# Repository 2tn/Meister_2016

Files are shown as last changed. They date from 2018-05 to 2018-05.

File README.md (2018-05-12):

# Meister_2016
2016年度Meister鳥人間プロジェクトに搭載した飛行ロガー、「われのロガー3」のプログラム及び発注基板データ。



搭載したパーツは
- LPC11U35FHI33 (メインマイコン)
- MPU9250 (9軸センサー)
- MPL3115A2 (気圧センサー)
- NEO-7M (GPS)
- LTC4055 (LiPo充電制御チップ)
- TPS63001DRCT (3.3V DC/DCコンバーター)
- TWE-Lite (各搭載センサーとの通信用)

## われのロガー3
メインマイコンのプログラム。EMとFMのプロジェクトがあるが、FMのほうが最終的な完成版。
## 機速計
機速計のプログラム。よく覚えていない。
## 表示器 (7セグLED)
表示器のプログラム
## 表示器 (Android)
搭載したスマホ表示器のプログラム
## ダウンリンク
機体に積んであるスマホから、携帯回線経由で常時データをサーバーにアップロードしている。

このプログラムはそのデータを地上にいる観客がスマホで見るためのもの
## 基板
発注した基板データ、たくさんある…
- main_16

  われのロガー3の基板データ
- main_16_writer

  われのロガー3専用のデバッグ用機器、われのロガー3の下にはめてUSBでPCと接続することで、われのロガー3をデバッグできる。
  プログラムは、トラ技ARMライターのものをつかう。
- main_15

  2015年度の基板を回路図に落とし込んだもの  
- display

  表示器の回路設計図
- speedmeter

  機速計の回路設計図
- TWE-Lite_USB

  TWE LiteにUSB-UART変換チップをくっつけて、PCで使いやすくするための基板

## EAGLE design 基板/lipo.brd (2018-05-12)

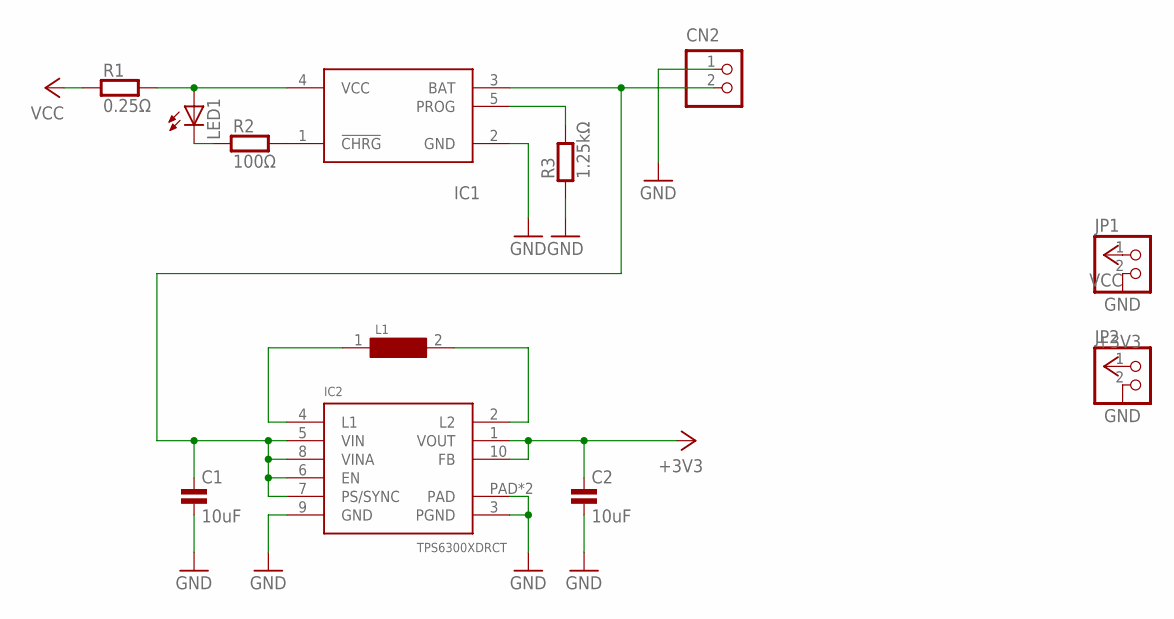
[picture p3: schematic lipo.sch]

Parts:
C1, C2: 10uF; 0603
CN2: S2B-PH-K-S
IC1: LTC4054; TSOT23-5
IC2: TPS6300XDRCT; S-PVSON-N10
JP1, JP2: PINHD-1X2; 1X02
L1: VLF4012ST
LED1: LEDSML0603; SML0603
R1: 0.25Ω; 0603
R2: 100Ω; 0603
R3: 1.25kΩ; 0603

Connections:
+3V3: C2.1, IC2.1 (VOUT), IC2.10 (FB), JP2.1
GND: C1.2, C2.2, CN2.1, IC1.2 (GND), IC2.3 (PGND), IC2.9 (GND), IC2.PAD, IC2.PAD@1 (PAD), JP1.2, JP2.2, R3.1
unnamed: IC1.5 (PROG), R3.2
unnamed: IC1.4 (VCC), LED1.A, R1.2
unnamed: IC1.1 (!CHRG!), R2.2
unnamed: LED1.C, R2.1
unnamed: IC2.4 (L1), L1.1
unnamed: IC2.2 (L2), L1.2
unnamed: C1.1, CN2.2, IC1.3 (BAT), IC2.5 (VIN), IC2.6 (EN), IC2.7 (PS/SYNC), IC2.8 (VINA)
VCC: JP1.1, R1.1

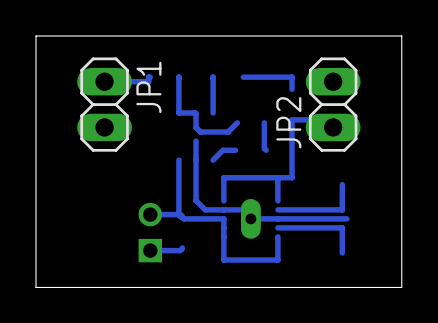
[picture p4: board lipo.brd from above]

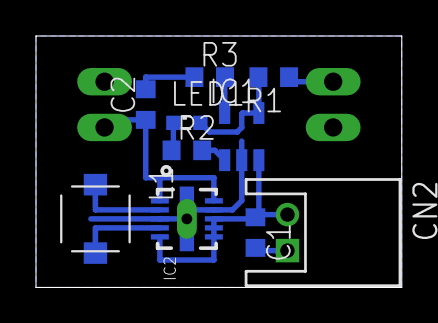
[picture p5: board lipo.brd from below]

Board: 2 copper layers, 20.3 x 14.0 mm, 12 parts (10 on the bottom side), 10 nets.

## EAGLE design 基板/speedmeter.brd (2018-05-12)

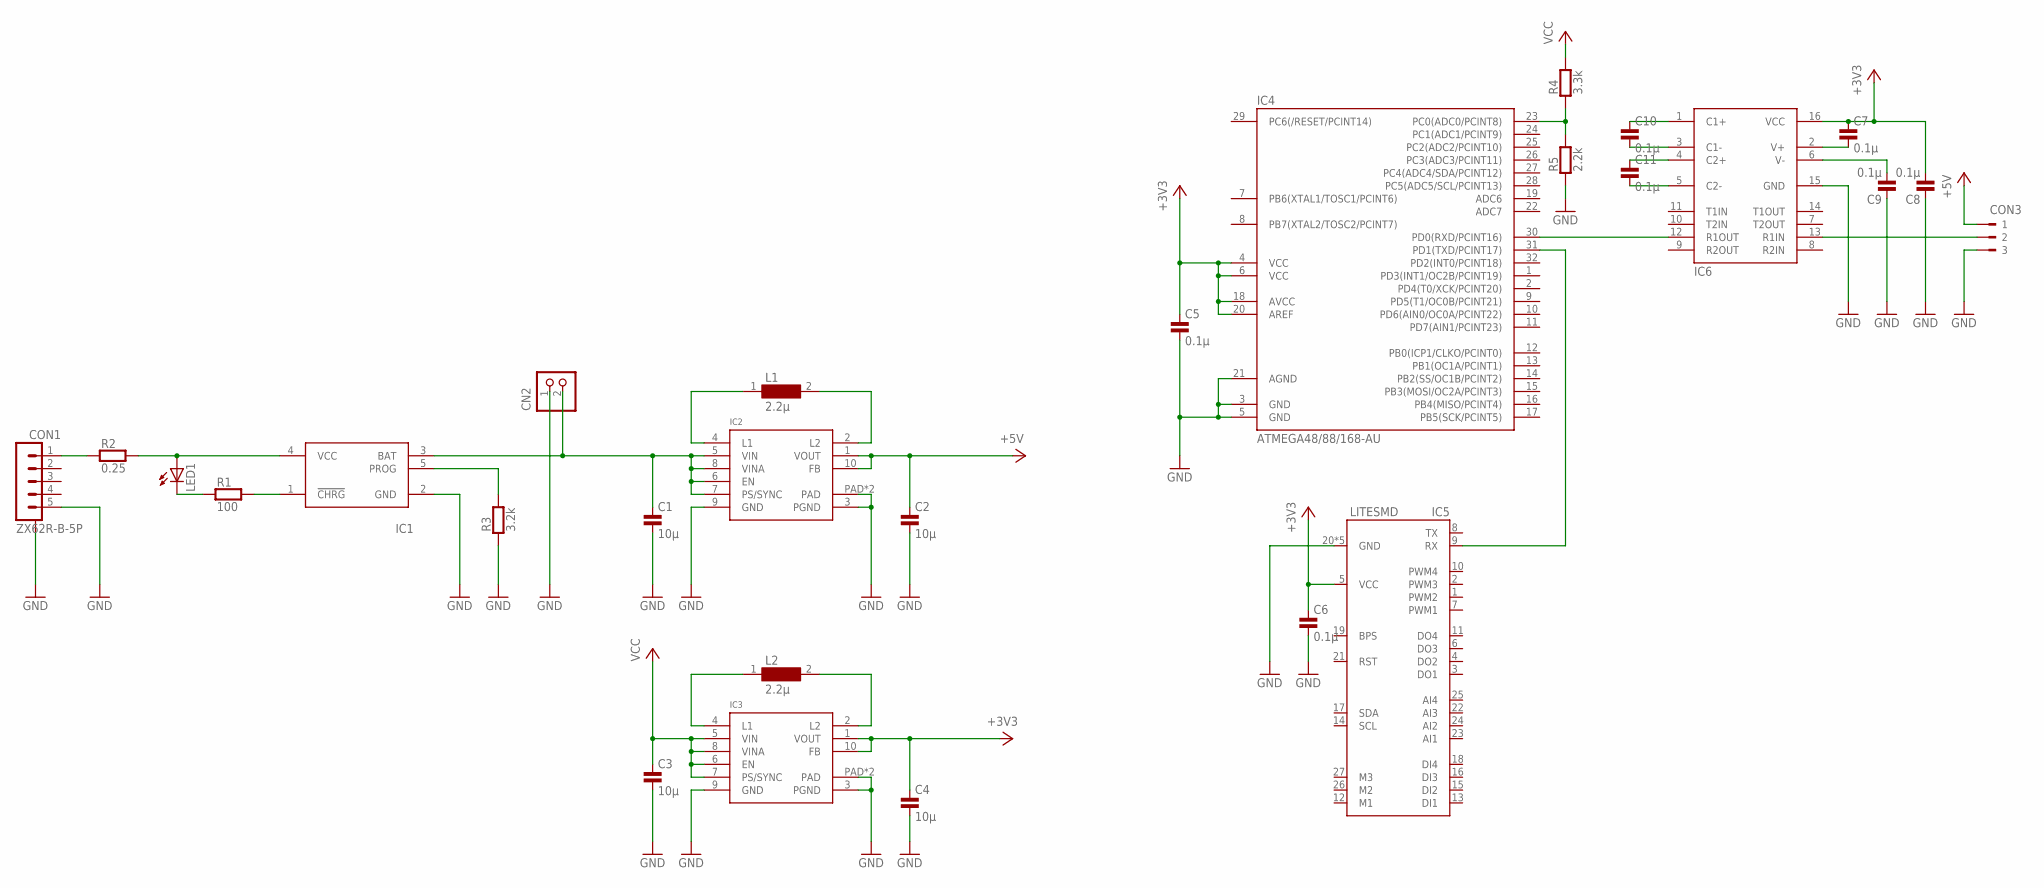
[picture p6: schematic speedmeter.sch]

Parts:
C1, C2, C3, C4: 10μ; 0603
C5, C6, C7, C8, C9, C10, C11: 0.1μ; 0603
CN2: S2B-PH-K-S
CON1: ZX62R-B-5P; MICRO-B
CON3: 180-3
IC1: LTC4054; TSOT23-5
IC2, IC3: TPS6300XDRCT; S-PVSON-N10
IC4: ATMEGA48/88/168-AU; TQFP32-08
IC5: LITESMD; LITE
IC6: ADM3202ARN; SOP16
L1, L2: 2.2μ; VLF4012ST
LED1: LEDSML0603; SML0603
R1: 100; 0603
R2: 0.25; 0603
R3: 3.2k; 0603
R4: 3.3k; 0603
R5: 2.2k; 0603

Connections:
+3V3: C4.1, C5.1, C6.1, C7.1, C8.2, IC3.1 (VOUT), IC3.10 (FB), IC4.4 (VCC), IC4.6 (VCC), IC4.18 (AVCC), IC4.20 (AREF), IC5.5 (VCC), IC6.16 (VCC)
+5V: C2.1, CON3.1, IC2.1 (VOUT), IC2.10 (FB)
GND: C1.2, C2.2, C3.2, C4.2, C5.2, C6.2, C8.1, C9.1, CN2.1, CON1.5 (1.VBUS), CON1.CASE@1, CON1.CASE@2, CON1.CASE@3, CON1.CASE@4, CON3.3, IC1.2 (GND), IC2.3 (PGND), IC2.9 (GND), IC2.PAD, IC2.PAD@1 (PAD), IC3.3 (PGND), IC3.9 (GND), IC3.PAD, IC3.PAD@1 (PAD), IC4.3 (GND), IC4.5 (GND), IC4.21 (AGND), IC5.20 (GND), IC5.28 (GND), IC5.30 (GND), IC5.31 (GND), IC5.32 (GND), IC6.15 (GND), R3.1, R5.1
unnamed: CON1.1 (5.GND), R2.1
unnamed: IC1.4 (VCC), LED1.A, R2.2
unnamed: LED1.C, R1.1
unnamed: IC1.1 (!CHRG!), R1.2
unnamed: IC1.5 (PROG), R3.2
unnamed: IC2.4 (L1), L1.1
unnamed: IC2.2 (L2), L1.2
unnamed: CON3.2, IC6.13 (R1IN)
unnamed: IC3.4 (L1), L2.1
unnamed: IC3.2 (L2), L2.2
unnamed: IC4.23 (PC0(ADC0/PCINT8)), R4.1, R5.2
unnamed: IC4.31 (PD1(TXD/PCINT17)), IC5.9 (RX)
unnamed: C7.2, IC6.2 (V+)
unnamed: C9.2, IC6.6 (V-)
unnamed: C10.1, IC6.1 (C1+)
unnamed: C10.2, IC6.3 (C1-)
unnamed: C11.1, IC6.4 (C2+)
unnamed: C11.2, IC6.5 (C2-)
unnamed: IC4.30 (PD0(RXD/PCINT16)), IC6.12 (R1OUT)
VCC: C1.1, C3.1, CN2.2, IC1.3 (BAT), IC2.5 (VIN), IC2.6 (EN), IC2.7 (PS/SYNC), IC2.8 (VINA), IC3.5 (VIN), IC3.6 (EN), IC3.7 (PS/SYNC), IC3.8 (VINA), R4.2

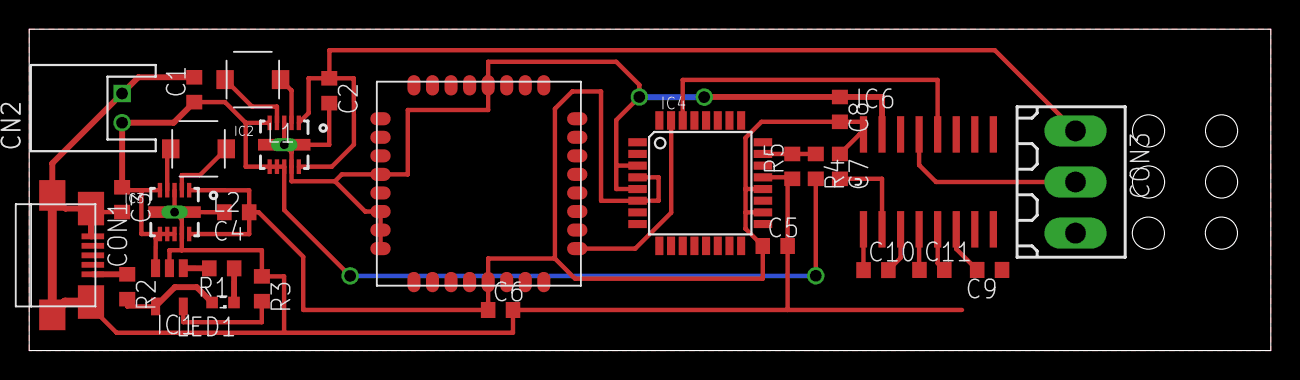
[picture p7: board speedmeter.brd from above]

Board: 2 copper layers, 85.0 x 22.0 mm, 28 parts (0 on the bottom side), 23 nets.

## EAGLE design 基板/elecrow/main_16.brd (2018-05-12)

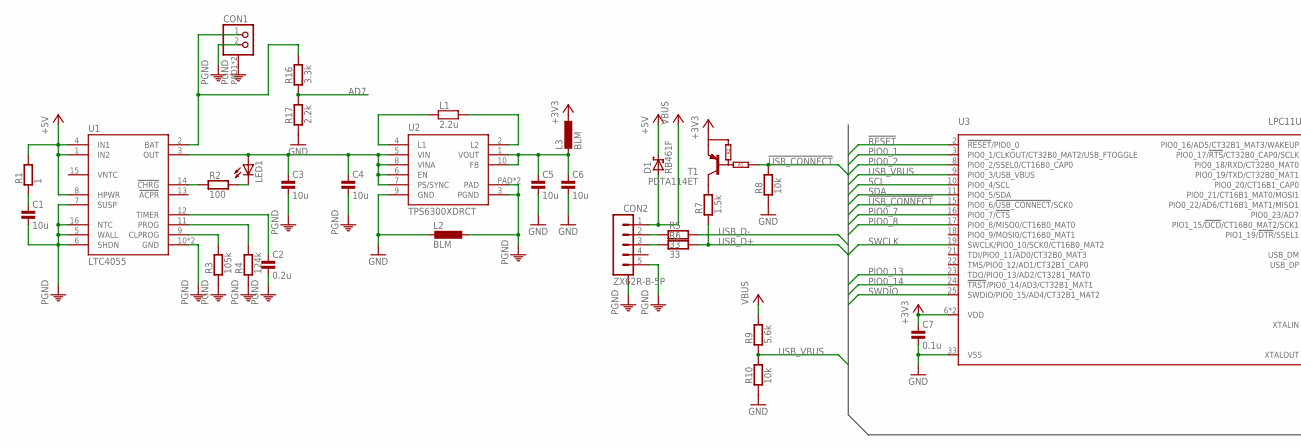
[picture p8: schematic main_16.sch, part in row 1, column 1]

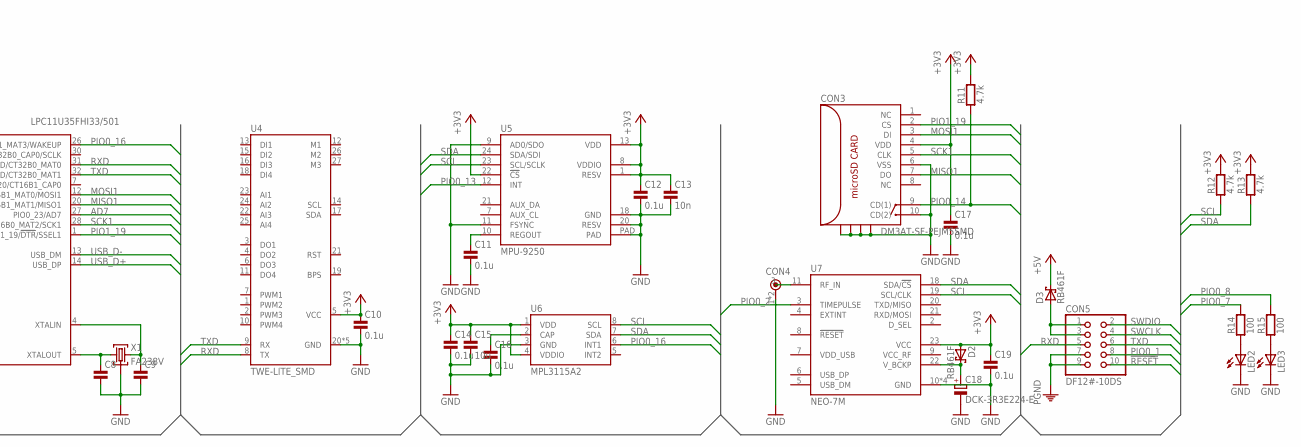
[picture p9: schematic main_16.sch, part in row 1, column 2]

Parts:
C1, C3, C4, C5, C6: 10u; 0603
C2: 0.2u; 0402
C7, C10, C11, C12, C14, C16, C17, C19: 0.1u; 0402
C8, C9: C0402; 0402
C13: 10n; 0402
C15: 10u; 0402
C18: DCK-3R3E224-E
CON1: JST-PH2
CON2: ZX62R-B-5P; MICRO-B
CON3: DM3AT-SF-PEJM5SMD; DM3AT-SF-PEJM5
CON4: U.FL; U.FL-R-SMT-1
CON5: DF12#-10DS; DF12A-10DS
D1, D2, D3: RB461F; UMD3
L1: 2.2u; VLF4012ST
L2, L3: BLM; C0603K
LED1, LED2, LED3: LEDSML0603; SML0603
R1: 1; 0402
R2, R14, R15: 100; 0402
R3: 105k; 0402
R4: 124k; 0402
R5, R6: 33; 0402
R7: 1.5k; 0402
R8, R10: 10k; 0402
R9: 5.6k; 0402
R11, R12, R13: 4.7k; 0402
R16: 3.3k; 0402
R17: 2.2k; 0402
T1: PDTA114ET; SOT23
U1: LTC4055; QFN16
U2: TPS6300XDRCT; S-PVSON-N10
U3: LPC11U35FHI33/501; SOT617-3
U4: TWE-LITE_SMD; LITE
U5: MPU-9250
U6: MPL3115A2
U7: NEO-7M
X1: FA238V; V66RA

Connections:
!RESET!: CON5.10, U3.2 (!RESET!/PIO0_0)
!USB_CONNECT!: R8.2, T1.1 (INPUT), U3.15 (PIO0_6/!USB_CONNECT!/SCK0)
+3V3: C7.1, C10.1, C12.1, C13.1, C14.1, C15.1, C17.1, C19.1, CON3.4 (VDD), D2.2 (A), L3.1, R11.2, R12.2, R13.2, T1.2 (E), U3.6 (VDD), U3.29 (VDD), U4.5 (VCC), U5.1 (RESV), U5.8 (VDDIO), U5.13 (VDD), U5.22 (!CS!), U6.1 (VDD), U6.4 (VDDIO), U7.23 (VCC)
+5V: D1.3 (C), D3.3 (C), R1.2, U1.1 (IN2), U1.4 (IN1), U1.8 (HPWR)
AD7: R16.1, R17.2, U3.27 (PIO0_23/AD7)
GND: C5.2, C6.2, C7.2, C8.2, C9.2, C10.2, C11.2, C12.2, C13.2, C14.2, C15.2, C16.2, C17.2, C18.1 (-), C19.2, CON3.6 (VSS), CON3.10 (CD(2)), CON3.P$10, CON3.P$11, CON3.P$12, CON3.P$14, CON4.1 (GND), CON4.2 (GND), L2.2, LED2.C, LED3.C, R8.1, R10.1, R17.1, U2.9 (GND), U3.33 (VSS), U4.20 (GND), U4.28 (GND), U4.30 (GND), U4.31 (GND), U4.32 (GND), U5.9 (AD0/SDO), U5.11 (FSYNC), U5.18 (GND), U5.20 (RESV), U5.PAD, U6.3 (GND), U7.10 (GND), U7.12 (GND), U7.13 (GND), U7.24 (GND), X1.P2GND (GND), X1.P4GND (GND)
MISO1: CON3.7 (DO), U3.20 (PIO0_22/AD6/CT16B1_MAT1/MISO1)
MOSI1: CON3.3 (DI), U3.12 (PIO0_21/CT16B1_MAT0/MOSI1)
unnamed: C8.1, U3.5 (XTALOUT), X1.P1X1 (X1)
unnamed: CON2.2 (2.D-), R5.1
unnamed: C9.1, U3.4 (XTALIN), X1.P3X2 (X2)
unnamed: CON2.3 (3.D+), R6.1
unnamed: R7.2, T1.3 (C)
unnamed: LED3.A, R15.1
unnamed: CON4.3 (RF), U7.11 (RF_IN)
unnamed: C16.1, U6.2 (CAP)
unnamed: L1.2, U2.2 (L2)
unnamed: C11.1, U5.10 (REGOUT)
unnamed: L1.1, U2.4 (L1)
unnamed: LED2.A, R14.1
unnamed: C1.1, R1.1
unnamed: C5.1, C6.1, L3.2, U2.1 (VOUT), U2.10 (FB)
unnamed: CON5.1, CON5.3, D3.2 (A)
unnamed: R3.2, U1.9 (CLPROG)
unnamed: R4.2, U1.11 (PROG)
unnamed: C2.1, U1.12 (TIMER)
unnamed: R2.1, U1.14 (!CHRG!)
unnamed: LED1.C, R2.2
unnamed: C3.1, C4.1, LED1.A, U1.3 (OUT), U2.5 (VIN), U2.6 (EN), U2.7 (PS/SYNC), U2.8 (VINA)
unnamed: CON1.1, R16.2, U1.2 (BAT)
unnamed: C18.2 (+), D2.3 (C), U7.22 (V_BCKP)
PGND: C1.2, C2.2, C3.2, C4.2, CON1.2, CON1.PAD1, CON1.PAD2, CON2.5 (5.GND), CON2.CASE@1, CON2.CASE@2, CON2.CASE@3, CON2.CASE@4, CON5.7, CON5.9, L2.1, R3.1, R4.1, U1.5 (WALL), U1.6 (SHDN), U1.7 (SUSP), U1.10 (GND), U1.16 (NTC), U1.PAD (GND), U2.3 (PGND), U2.PAD, U2.PAD@1 (PAD)
PIO0_1: CON5.8, U3.3 (PIO0_1/CLKOUT/CT32B0_MAT2/USB_FTOGGLE)
PIO0_2: U3.8 (PIO0_2/SSEL0/CT16B0_CAP0), U7.3 (TIMEPULSE)
PIO0_7: R14.2, U3.16 (PIO0_7/!CTS!)
PIO0_8: R15.2, U3.17 (PIO0_8/MISO0/CT16B0_MAT0)
PIO0_13: U3.23 (TDO/PIO0_13/AD2/CT32B1_MAT0), U5.12 (INT)
PIO0_14: CON3.9 (CD(1)), R11.1, U3.24 (!TRST!/PIO0_14/AD3/CT32B1_MAT1)
PIO0_16: U3.26 (PIO0_16/AD5/CT32B1_MAT3/WAKEUP), U6.6 (INT1)
PIO1_19: CON3.2 (CS), U3.1 (PIO1_19/!DTR!/SSEL1)
RXD: CON5.5, U3.31 (PIO0_18/RXD/CT32B0_MAT0), U4.8 (TX)
SCK1: CON3.5 (CLK), U3.28 (PIO1_15/!DCD!/CT16B0_MAT2/SCK1)
SCL: R12.1, U3.10 (PIO0_4/SCL), U5.23 (SCL/SCLK), U6.8 (SCL), U7.19 (SCL/CLK)
SDA: R13.1, U3.11 (PIO0_5/SDA), U5.24 (SDA/SDI), U6.7 (SDA), U7.18 (SDA/!CS!)
SWCLK: CON5.4, U3.19 (SWCLK/PIO0_10/SCK0/CT16B0_MAT2)
SWDIO: CON5.2, U3.25 (SWDIO/PIO0_15/AD4/CT32B1_MAT2)
TXD: CON5.6, U3.32 (PIO0_19/TXD/CT32B0_MAT1), U4.9 (RX)
USB_D+: R6.2, R7.1, U3.14 (USB_DP)
USB_D-: R5.2, U3.13 (USB_DM)
USB_VBUS: R9.1, R10.2, U3.9 (PIO0_3/USB_VBUS)
VBUS: CON2.1 (1.VBUS), D1.2 (A), R9.2
VDD_USB: U7.7 (VDD_USB)
VNTC: U1.15 (VNTC)

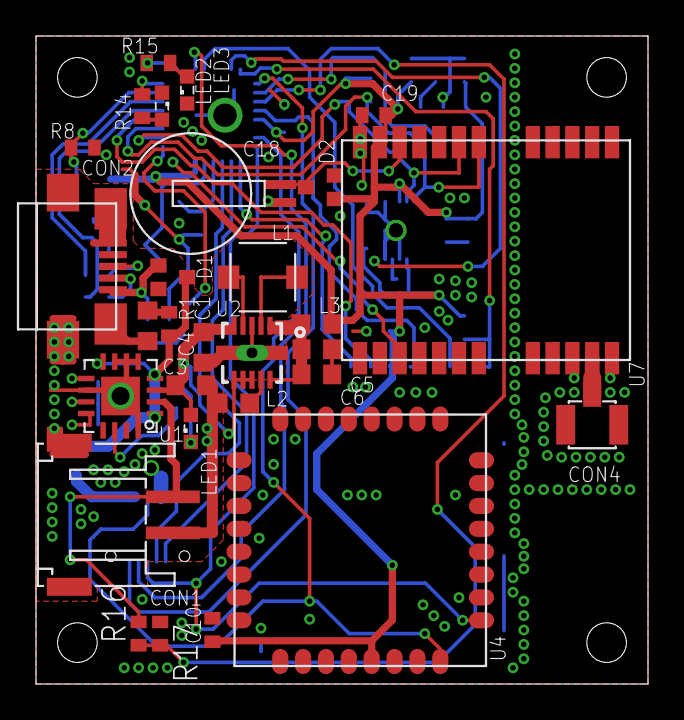
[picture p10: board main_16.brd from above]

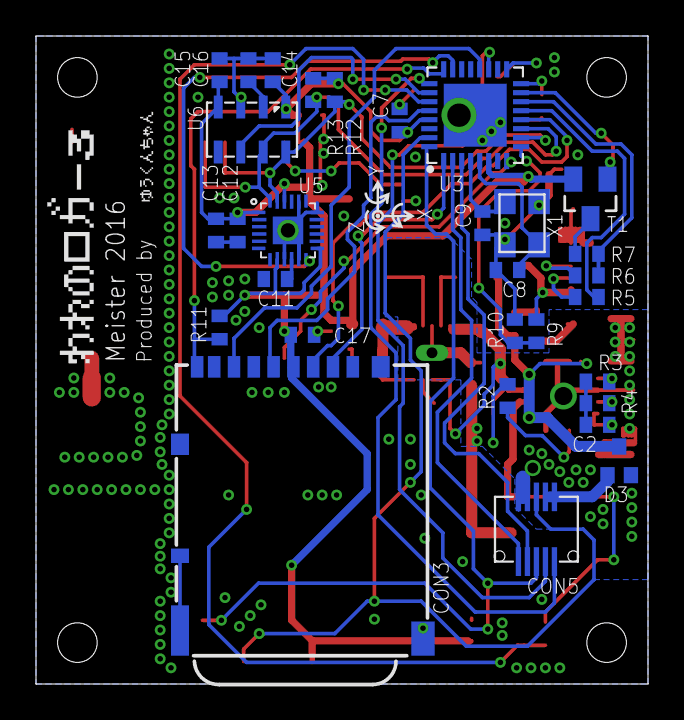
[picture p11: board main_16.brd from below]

Board: 2 copper layers, 34.0 x 36.0 mm, 60 parts (31 on the bottom side), 51 nets.

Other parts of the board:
U$1: DIRECTION

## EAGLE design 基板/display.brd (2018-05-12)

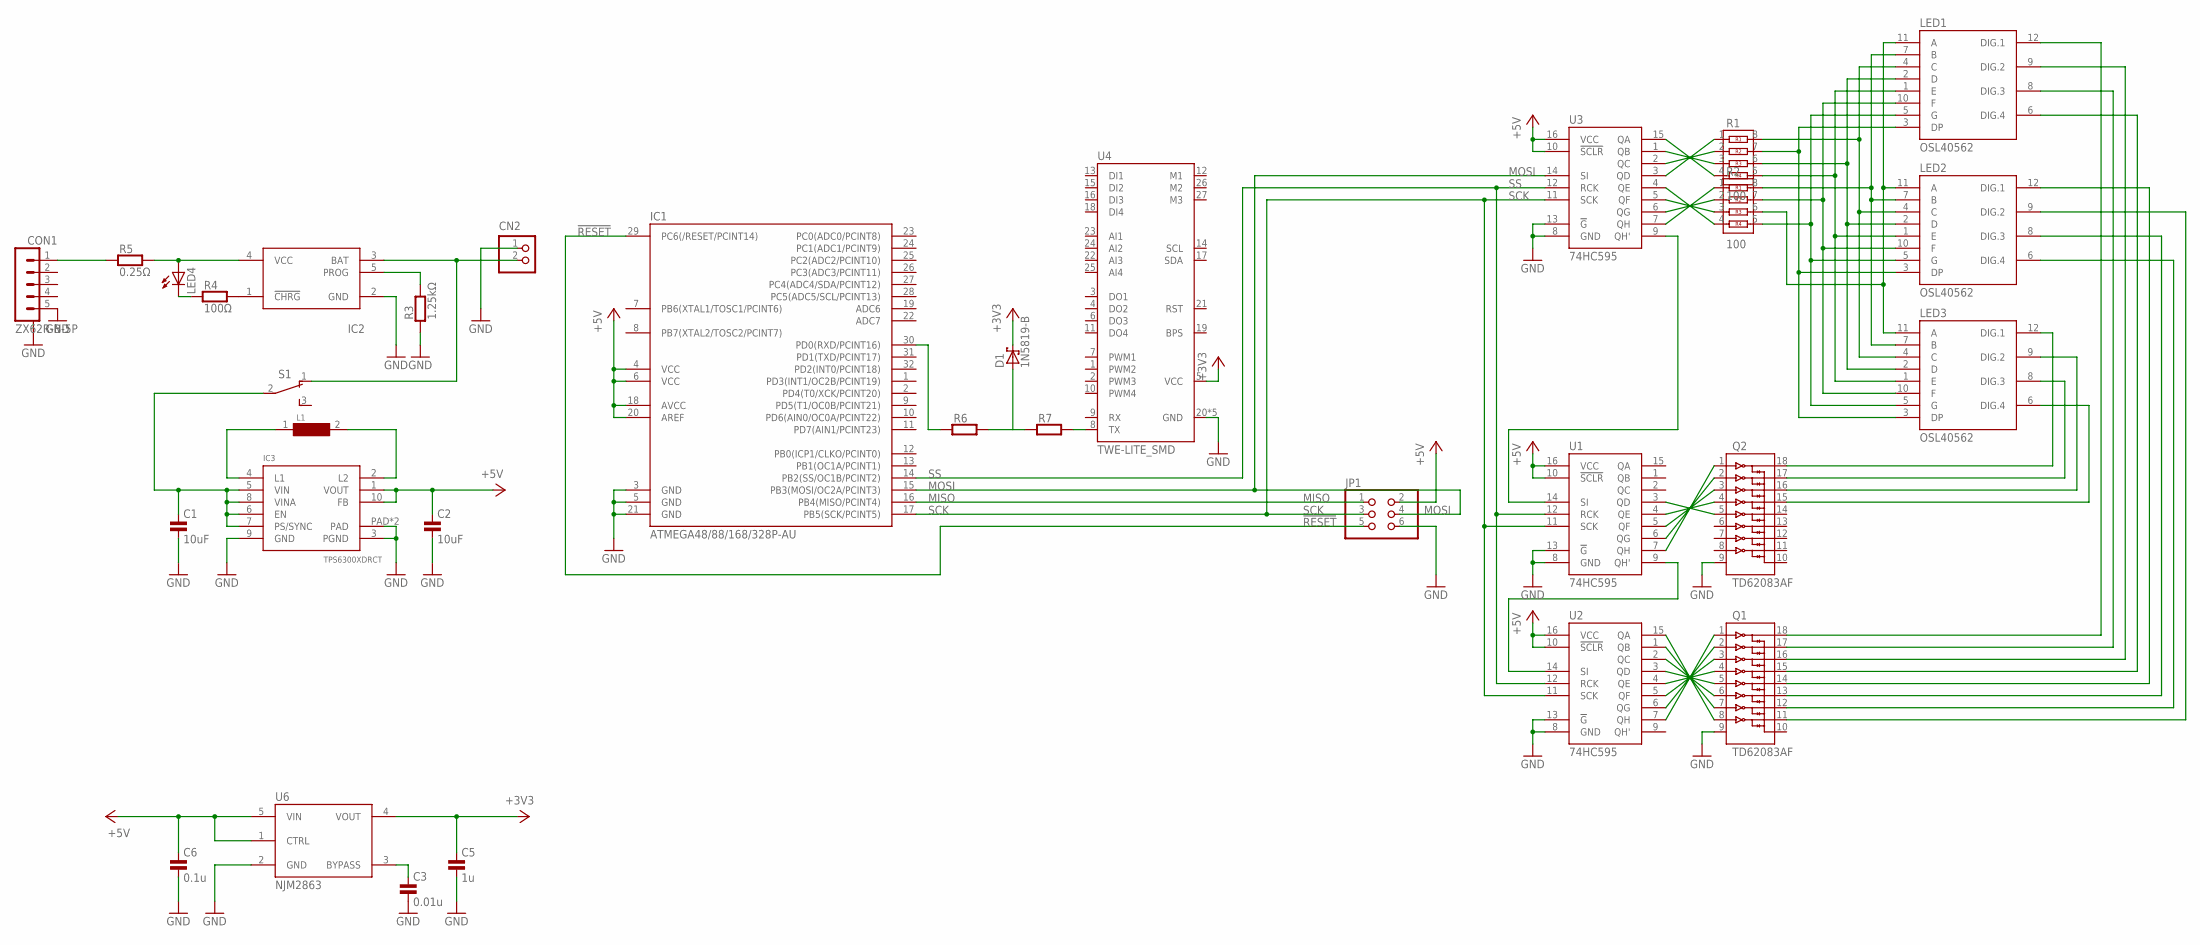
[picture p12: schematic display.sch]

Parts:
C1, C2: 10uF; 0603@1
C3: 0.01u; 0603@1
C5: 1u; 0603@1
C6: 0.1u; 0603@1
CN2: S2B-PH-K-S
CON1: ZX62R-B-5P; MICRO-B
D1: 1N5819-B; DO41-7.6
IC1: ATMEGA48/88/168/328P-AU; TQFP32
IC2: LTC4054; TSOT23-5
IC3: TPS6300XDRCT; S-PVSON-N10
JP1: PINHD-2X3; 2X03
L1: VLF4012ST
LED1, LED2, LED3: OSL40562; 7SEG_4DIG
LED4: LEDSML0603; SML0603
Q1, Q2: TD62083AF; SOP18
R1, R2: 100; BCN164AB
R3: 1.25kΩ; 0603
R4: 100Ω; 0603
R5: 0.25Ω; 0603
R6, R7: R0204/5; 0204/5
S1: SS-12D00
U1, U2, U3: 74HC595; SOP16
U4: TWE-LITE_SMD; LITE
U6: NJM2863; SOT23_5PIN

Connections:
!RESET!: IC1.29 (PC6(/RESET/PCINT14)), JP1.5
+3V2: C1.1, IC3.5 (VIN), IC3.6 (EN), IC3.7 (PS/SYNC), IC3.8 (VINA), S1.2
+3V3: C5.1, D1.C, U4.5 (VCC), U6.4 (VOUT)
+5V: C2.1, C6.1, IC1.4 (VCC), IC1.6 (VCC), IC1.18 (AVCC), IC1.20 (AREF), IC3.1 (VOUT), IC3.10 (FB), JP1.2, U1.10 (!SCLR!), U1.16 (VCC), U2.10 (!SCLR!), U2.16 (VCC), U3.10 (!SCLR!), U3.16 (VCC), U6.1 (CTRL), U6.5 (VIN)
GND: C1.2, C2.2, C3.2, C5.2, C6.2, CN2.1, CON1.5 (5.GND), CON1.CASE@1, CON1.CASE@2, CON1.CASE@3, CON1.CASE@4, IC1.3 (GND), IC1.5 (GND), IC1.21 (GND), IC2.2 (GND), IC3.3 (PGND), IC3.9 (GND), IC3.PAD, IC3.PAD@1 (PAD), JP1.6, Q1.9 (GND), Q2.9 (GND), R3.1, U1.8 (GND), U1.13 (!G!), U2.8 (GND), U2.13 (!G!), U3.8 (GND), U3.13 (!G!), U4.20 (GND), U4.28 (GND), U4.30 (GND), U4.31 (GND), U4.32 (GND), U6.2 (GND)
MISO: IC1.16 (PB4(MISO/PCINT4)), JP1.1
MOSI: IC1.15 (PB3(MOSI/OC2A/PCINT3)), JP1.4, U3.14 (SI)
unnamed: LED1.11 (A), LED2.11 (A), LED3.11 (A), R2.6
unnamed: LED1.7 (B), LED2.7 (B), LED3.7 (B), R2.8
unnamed: LED1.4 (C), LED2.4 (C), LED3.4 (C), R1.8
unnamed: LED1.2 (D), LED2.2 (D), LED3.2 (D), R1.6
unnamed: LED1.1 (E), LED2.1 (E), LED3.1 (E), R1.5
unnamed: LED1.10 (F), LED2.10 (F), LED3.10 (F), R2.7
unnamed: LED1.5 (G), LED2.5 (G), LED3.5 (G), R2.5
unnamed: LED1.3 (DP), LED2.3 (DP), LED3.3 (DP), R1.7
unnamed: CN2.2, IC2.3 (BAT), S1.1 (O)
unnamed: C3.1, U6.3 (BYPASS)
unnamed: Q2.5 (I5), U1.3 (QD)
unnamed: Q2.4 (I4), U1.4 (QE)
unnamed: Q2.3 (I3), U1.5 (QF)
unnamed: Q2.2 (I2), U1.6 (QG)
unnamed: Q2.1 (I1), U1.7 (QH)
unnamed: LED2.9 (DIG.2), Q1.11 (O8)
unnamed: LED2.8 (DIG.3), Q1.13 (O6)
unnamed: LED2.6 (DIG.4), Q1.12 (O7)
unnamed: LED2.12 (DIG.1), Q1.14 (O5)
unnamed: LED1.6 (DIG.4), Q1.15 (O4)
unnamed: LED1.12 (DIG.1), Q1.18 (O1)
unnamed: LED1.8 (DIG.3), Q1.17 (O2)
unnamed: LED1.9 (DIG.2), Q1.16 (O3)
unnamed: LED3.12 (DIG.1), Q2.18 (O1)
unnamed: LED3.9 (DIG.2), Q2.16 (O3)
unnamed: LED3.8 (DIG.3), Q2.17 (O2)
unnamed: LED3.6 (DIG.4), Q2.15 (O4)
unnamed: Q1.8 (I8), U2.15 (QA)
unnamed: Q1.7 (I7), U2.1 (QB)
unnamed: Q1.6 (I6), U2.2 (QC)
unnamed: Q1.5 (I5), U2.3 (QD)
unnamed: Q1.4 (I4), U2.4 (QE)
unnamed: Q1.3 (I3), U2.5 (QF)
unnamed: Q1.2 (I2), U2.6 (QG)
unnamed: Q1.1 (I1), U2.7 (QH)
unnamed: U1.9 (QH'), U2.14 (SI)
unnamed: R1.4, U3.15 (QA)
unnamed: R1.3, U3.1 (QB)
unnamed: R1.2, U3.2 (QC)
unnamed: R1.1, U3.3 (QD)
unnamed: R2.4, U3.4 (QE)
unnamed: R2.3, U3.5 (QF)
unnamed: R2.2, U3.6 (QG)
unnamed: R2.1, U3.7 (QH)
unnamed: U1.14 (SI), U3.9 (QH')
unnamed: IC1.30 (PD0(RXD/PCINT16)), R6.1
unnamed: IC2.5 (PROG), R3.2
unnamed: IC2.4 (VCC), LED4.A, R5.2
unnamed: IC2.1 (!CHRG!), R4.2
unnamed: LED4.C, R4.1
unnamed: IC3.4 (L1), L1.1
unnamed: IC3.2 (L2), L1.2
unnamed: D1.A, R6.2, R7.1
unnamed: R7.2, U4.8 (TX)
unnamed: CON1.1 (1.VBUS), R5.1
SCK: IC1.17 (PB5(SCK/PCINT5)), JP1.3, U1.11 (SCK), U2.11 (SCK), U3.11 (SCK)
SS: IC1.14 (PB2(SS/OC1B/PCINT2)), U1.12 (RCK), U2.12 (RCK), U3.12 (RCK)

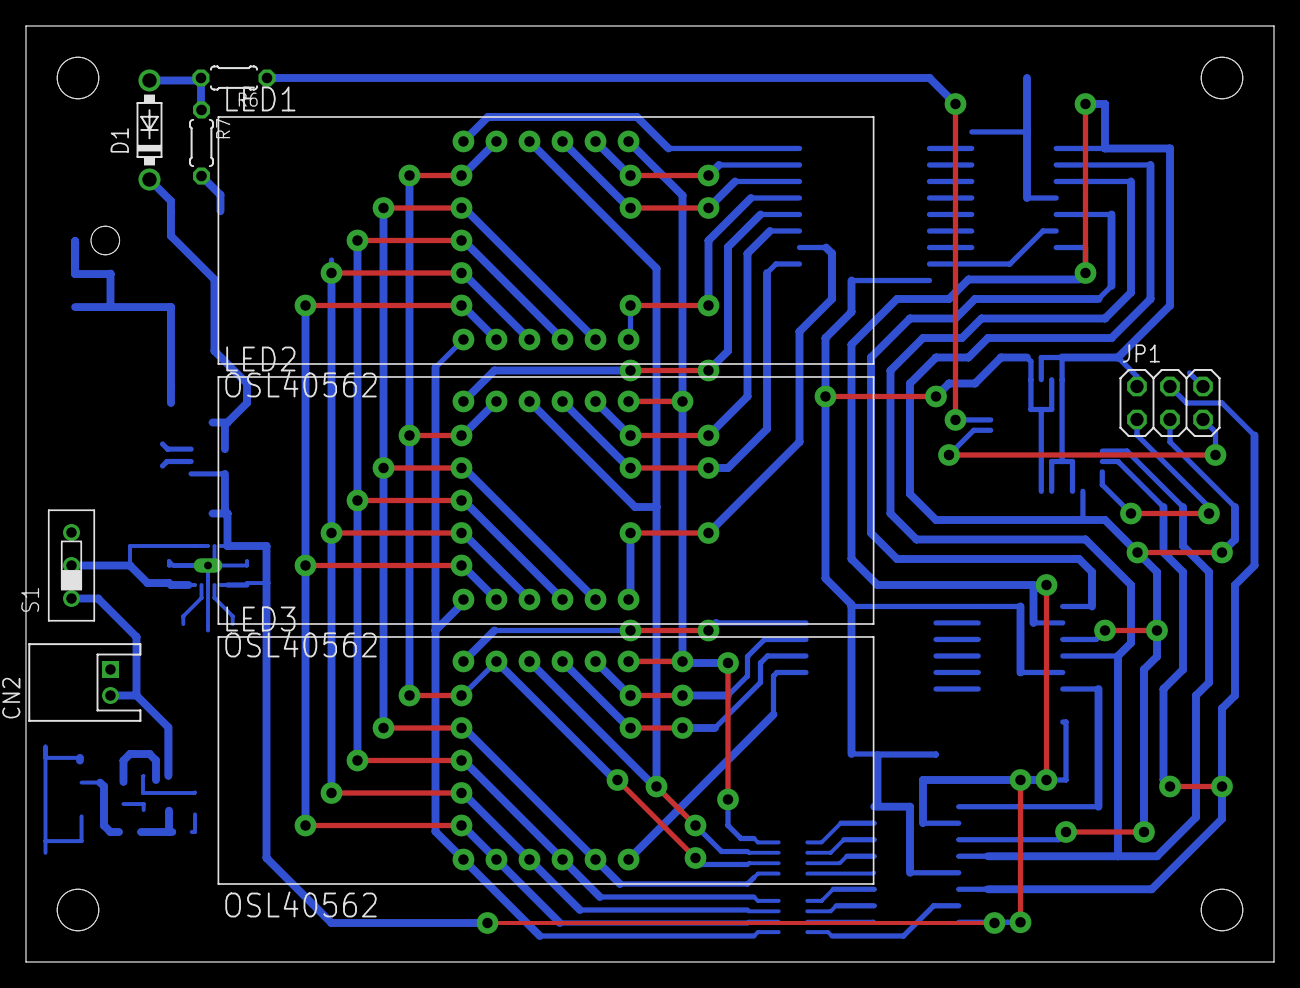
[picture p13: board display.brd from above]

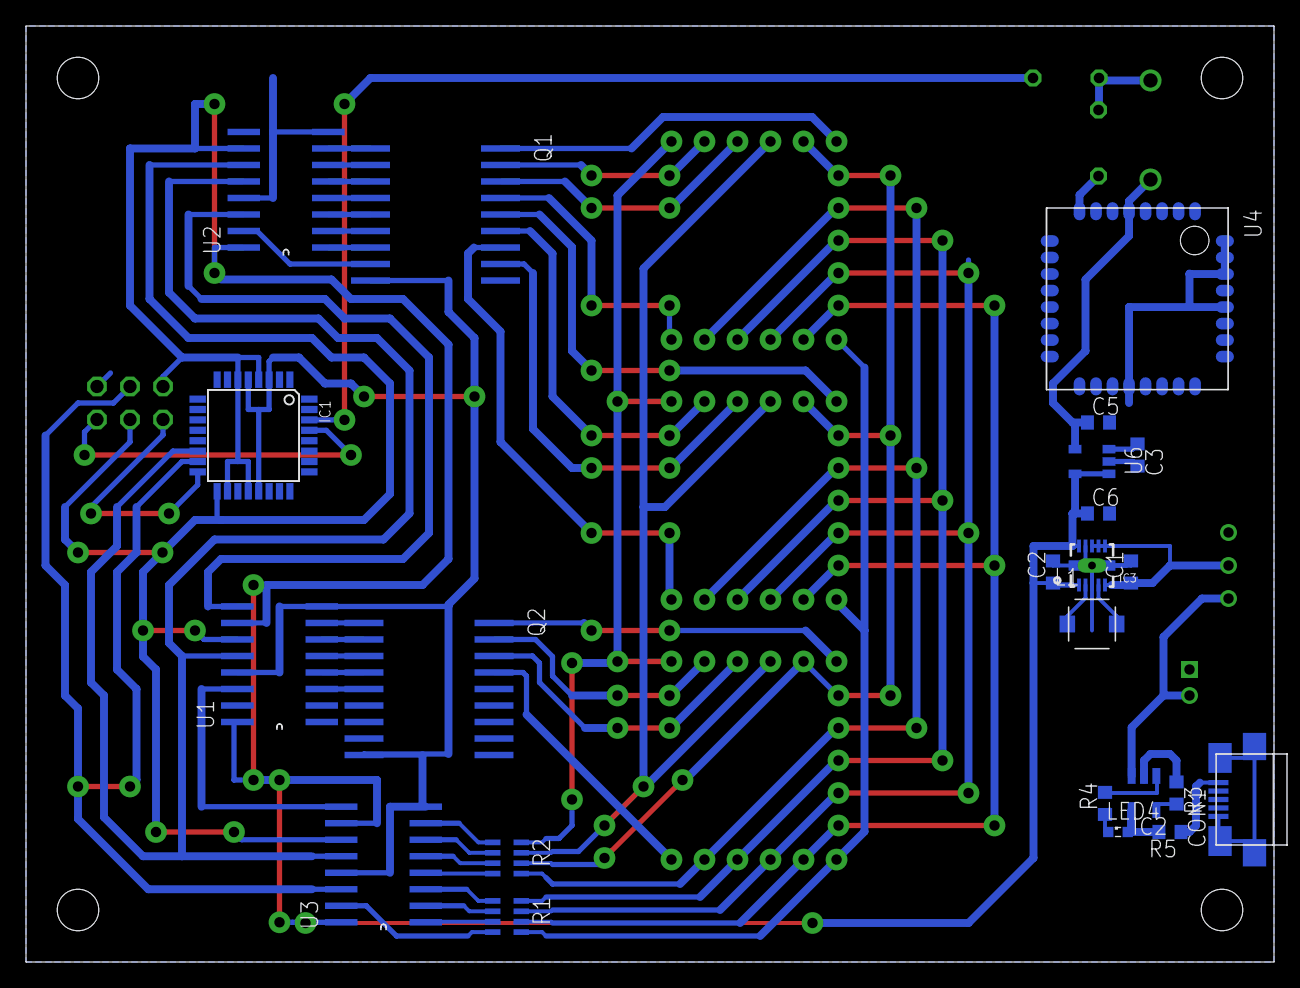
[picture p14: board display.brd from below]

Board: 2 copper layers, 96.0 x 72.0 mm, 32 parts (23 on the bottom side), 64 nets.

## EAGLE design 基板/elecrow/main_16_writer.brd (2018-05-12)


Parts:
C1: 0.1u; C0402
C2, C3: 8P; C0402
C4, C5: 1u; C0402
C6: PSW; C3225
CON1: ZX62R-B-5P; MICRO-B
CON2: DF12#-10DP; DF12D-10DP
LED1, LED2, LED3: LEDSML0603; SML0603
Q1: PDTA114ET; SOT23
Q2: MIC550X; SOT23_5PIN
R1, R3, R4, R9: 10k; R0402
R2, R12, R13, R15, R16, R17: 270; R0402
R5, R10, R11: 1.5k; R0402
R6, R7: 33; R0402
R8: 5.6k; R0402
R14: 750; R0402
SW1, SW2: SKRPACE010
U1: LPC11U35FHI33/501; SOT617-3
U$1, U$2, U$3: TESTPAD
X1: FA238V; V66RA

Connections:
!USB_CONNECT!: Q1.1 (INPUT), R4.2, U1.15 (PIO0_6/!USB_CONNECT!/SCK0)
BOOT: CON2.8, R13.2
D+USB: CON1.3 (3.D+), R5.1, R6.2
D-USB: CON1.2 (4.ID), R7.2
GND: C1.2, C2.2, C3.2, C4.2, C5.2, CON1.5 (1.VBUS), CON1.CASE@1 (1), CON1.CASE@2 (2), CON1.CASE@3 (3), CON1.CASE@4 (4), CON2.7, CON2.9, LED3.C, Q2.2 (GND), R4.1, R9.1, SW1.1, SW1.2, SW2.1, SW2.2, U1.33 (VSS), X1.P2GND (GND), X1.P4GND (GND)
unnamed: LED1.C, R10.1
unnamed: C2.1, U1.5 (XTALOUT), X1.P1X1 (X1)
unnamed: C3.1, U1.4 (XTALIN), X1.P3X2 (X2)
unnamed: C5.1, C6.2, Q2.5 (VOUT)
unnamed: R12.1, SW1.3 (S), SW1.4 (S)
unnamed: Q1.3 (C), R5.2
unnamed: R6.1, U1.14 (USB_DP)
unnamed: R7.1, U1.13 (USB_DM)
unnamed: CON2.10, R17.1
unnamed: LED2.C, R11.1
unnamed: R13.1, SW2.3 (S), SW2.4 (S)
unnamed: U1.2 (!RESET!/PIO0_0), U$3.P$1
unnamed: CON2.2, R15.1
unnamed: CON2.4, R16.1
unnamed: LED3.A, R14.2
PIO0_2: R2.2, U1.8 (PIO0_2/SSEL0/CT16B0_CAP0)
PIO0_16: R3.1, U1.26 (PIO0_16/AD5/CT32B1_MAT3/WAKEUP)
PIO0_20: R10.2, U1.7 (PIO0_20/CT16B1_CAP0)
PIO0_21: R11.2, U1.12 (PIO0_21/CT16B1_MAT0)
RXD: CON2.5, U$2.P$1
TARGET_!RESET!: R1.2, R2.1, R12.2, R17.2, U1.3 (PIO0_1/CLKOUT/CT32B0_MAT2/USB_FTOGGLE)
TARGET_SWCLK: R16.2, U1.16 (PIO0_7/!CTS!)
TARGET_SWDIO: R15.2, U1.17 (PIO0_8/MISO0/CT16B0_MAT0)
TXD: CON2.6, U$1.P$1
USB_VBUS: R8.1, R9.2, U1.9 (PIO0_3/USB_VBUS)
VCC: C4.1, CON1.1 (5.GND), CON2.1, CON2.3, Q2.1 (VIN), Q2.3 (EN), R8.2
VDD: C1.1, C6.1, LED1.A, LED2.A, Q1.2 (E), R1.1, R3.2, R14.1, U1.6 (VDD), U1.29 (VDD)



Board: 2 copper layers, 34.0 x 36.0 mm, 37 parts (12 on the bottom side), 32 nets.

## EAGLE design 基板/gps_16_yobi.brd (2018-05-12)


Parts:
C1, C2, C3, C4, C5, C7, C8: 0.1uF; 0603
C6: 470uF; C025-025X050
CON1: PINHD-1X3; 1X03
CON2, CON3: PINHD-1X2; 1X02
IC1: ADM3202ADM3202AN; IC16PIN
IC2: XBEE-PRO2MM; XBEE-ZB
IC3: 78MXXS

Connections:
+3V3: C3.1, C5.1, C8.1, IC1.16 (VCC), IC2.1 (VCC), IC3.OUT
+5V: C6.1, C7.1, CON1.2, CON3.1, IC3.IN
GND: C4.2, C5.2, C6.2, C7.2, C8.2, CON1.1, CON3.2, IC1.15 (GND), IC2.10 (GND), IC3.GND
GPS_OUT: CON1.3, CON2.1
unnamed: CON2.2, IC1.8 (R2IN)
unnamed: IC1.9 (R2OUT), IC2.3 (DIN/CONFIG)
unnamed: C2.1, IC1.4 (C2+)
unnamed: C2.2, IC1.5 (C2-)
unnamed: C1.1, IC1.1 (C1+)
unnamed: C1.2, IC1.3 (C1-)
unnamed: C4.1, IC1.6 (V-)
unnamed: C3.2, IC1.2 (V+)



Board: 2 copper layers, 30.5 x 82.5 mm, 14 parts (7 on the bottom side), 12 nets.

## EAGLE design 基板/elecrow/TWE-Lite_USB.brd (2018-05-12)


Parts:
C1, C2, C3, C4, C5, C6: C0402; 0402
CON1: ZX62R-B-5P; MICRO-B
L1: L-EU; C0603K
LED1, LED2: LEDSML0603; SML0603
PSW: 100m; C3225
R1, R2: R-EU_R0402; R0402
SW1: SKRPACE010
U1: TWE-LITE_SMD; LITE
U2: FT232RQ; QFN32

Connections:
+3V3: C3.1, C4.1, U1.5 (VCC), U2.1 (VCCIO), U2.16 (3V3OUT)
+5V: C5.1, C6.1, LED1.A, LED2.A, PSW.1, U2.19 (VCC)
GND: C1.2, C2.2, C3.2, C4.2, C5.2, C6.2, CON1.5 (1.VBUS), CON1.CASE@1, CON1.CASE@2, CON1.CASE@3, CON1.CASE@4, SW1.1, SW1.2, U1.20 (GND), U1.28 (GND), U1.30 (GND), U1.31 (GND), U1.32 (GND), U2.4 (GND), U2.17 (GND), U2.20 (GND), U2.24 (AGND), U2.26 (TEST), U2.PAD (GND)
unnamed: C1.1, CON1.2 (4.ID), U2.15 (USBDM)
unnamed: C2.1, CON1.3 (3.D+), U2.14 (USBDP)
unnamed: CON1.1 (5.GND), L1.2
unnamed: LED1.C, R1.2
unnamed: U1.9 (RX), U2.30 (TXD)
unnamed: U1.8 (TX), U2.2 (RXD)
unnamed: SW1.3 (S), SW1.4 (S), U1.2 (PWM3)
unnamed: L1.1, PSW.2
unnamed: LED2.C, R2.2
unnamed: R1.1, U2.22 (CBUS0)
unnamed: R2.1, U2.21 (CBUS1)



Board: 2 copper layers, 16.0 x 16.0 mm, 16 parts (15 on the bottom side), 14 nets.

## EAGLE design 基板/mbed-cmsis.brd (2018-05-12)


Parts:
IC1: MBED_NXP_LPC1768; MBED-KIT
JP1, JP2: PINHD-1X5; 1X05

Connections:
!RESET!: IC1.P$29 (P29), JP2.4
+3V3: IC1.VOUT (VO), JP2.1
+5V: IC1.VIN, JP1.1
D+: IC1.D+, JP1.3
D-: IC1.D-, JP1.2
GND: IC1.GND, JP1.5, JP2.5
NR: IC1.NR
SWCLK: IC1.P$22 (P22), JP2.3
SWDIO: IC1.P$21 (P21), JP2.2
VB: IC1.VB
VU: IC1.VU


Board: 2 copper layers, 100.0 x 80.0 mm, 3 parts (0 on the bottom side), 8 nets.

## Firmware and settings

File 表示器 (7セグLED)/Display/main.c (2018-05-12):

/*
* Display.c
*
* Created: 2016/07/24 15:01:49
* Author : Yusuke
*/
#define F_CPU	8000000UL
#include <avr/io.h>
#include <avr/interrupt.h>
#include <util/delay.h>
#include <avr//eeprom.h>
#include <stdbool.h>
#include <stdlib.h>
#include <string.h>

#define CS_LOW		PORTB &= ~(1<<PINB2);
#define CS_HIGH		PORTB |= 1<<PINB2;

#define ROULETTE	0

typedef struct{
	double value;
	bool enable;
}Display;

Display display[3];

//タイムアウト用にかぞえるやつ
uint16_t overflow=0;


#pragma region SPI_Function
void SPI_MasterInit(void)
{
	DDRB |= ((1<<DDB3)|(1<<DDB5)|(1<<DDB2));
	SPCR = (1<<SPE)|(1<<MSTR)|(1<<SPR0);
}
void SPI_MasterTransmit(char cData)
{
	SPDR = cData;
	while(!(SPSR & (1<<SPIF)));
}
#pragma endregion SPI_Function

#pragma region 7_segment
const uint8_t digits[] = {
	7,5,6,4,3,0,2,1,7,5,6,4
};
const uint8_t numerals[] = {
	0b11101011, // 0
	0b10001000, // 1
	0b10110011, // 2
	0b10111010, // 3
	0b11011000, // 4
	0b01111010, // 5
	0b01111011, // 6
	0b11101000, // 7
	0b11111011, // 8
	0b11111010, // 9
};
const uint8_t point = 0b00000100;
uint8_t number[12]={};

void num2bin(Display *display,uint8_t *binary){
	int i=0;
	int j=0;

	uint8_t _binary[12]={0};

	for (i = 0; i< 3; i++)
	{
		if (display->enable)
		{
			double demical;
			int integral;
			integral=(int)display->value;
			demical=display->value-(double)integral;
			int NoD =(int)log10(display->value) + 1;
			if (demical == 0.0f)
			{
				for (j = 0; j < NoD; j++){
					_binary[(i + 1) * 4 - j - 1] = numerals[integral % 10];
					integral /= 10;
				}
			}
			else
			{
				_binary[(i + 1) * 4 - 2] = numerals[integral % 10] | point;
				integral /= 10;
				for (j = 1; j < NoD; j++){
					_binary[(i + 1) * 4 - j - 2] = numerals[integral%10];
					integral /= 10;
				}
				_binary[(i + 1) * 4 - 1] = numerals[(int)round(demical * 10)];
			}
		}
		else
		{
			for (j=0;j<4;j++)
			{
				_binary[i*4+j]=0b00010000;
				_delay_us(100);
			}
		}

		display++;
	}
	for (i = 0; i < 12; i++)	*binary++=_binary[i];
}
#pragma endregion 7_segment

#pragma region Roulette
#if ROULETTE
uint8_t count=0;
uint16_t value[3];
ISR(TIMER1_COMPA_vect){
	int i;
	count++;
	if (count<60)
	{
		for (i=0;i<3;i++)
		{
			value[i]=rand()%10000;
		}
		OCR1A+=100;

		if (count<20){
			for (i=0;i<3;i++)
			{
				display[i].value=value[i];
			}
		}
		else if (count<30)
		{
			for (i=0;i<3;i++)
			{
				display[i].value=value[i]%1000+7000;
			}
		}
		else if (count<40)
		{
			for (i=0;i<3;i++)
			{
				display[i].value=(int)value[i]%100+7700;
			}
		}
		else if (count<60)
		{
			for (i=0;i<3;i++)
			{
				display[i].value=(int)value[i]%10+7770;
			}
		}
	}
	else
	{
		for (i=0;i<3;i++)
		{
			if((int)value[i]%3==0){
				display[i].value=7777;
			}
		}
		if (count==100)
		{
			for (i=0;i<3;i++)
			{
				display[i].enable=false;
				TIMSK1=0;
			}
		}
	}
}
void Timer_Init(void){
	TCCR1A=0;
	TCCR1B=0b01100;
	OCR1A=1;
	TIMSK1 = 0b0000010;
	sei();
}
#endif
#pragma endregion Roulette

#pragma region UART
void USART_Init(unsigned int baud)
{
	UBRR0H = (unsigned char)(baud>>8);
	UBRR0L = (unsigned char)baud;
	UCSR0A |= (1<<U2X0);
	UCSR0C = (3<<UCSZ00);
	UCSR0B = (1<<RXCIE0)|(1<<RXEN0)|(1<<TXEN0);
	sei();
}

#define BUFFERSIZE 256
uint8_t packetStatus = 0;
uint16_t dataPointer = 0;
uint8_t packet[BUFFERSIZE];
uint16_t packetLength = 0;

typedef enum {
	Simplicity = 0, Extention, Response
} BinaryFormat;

typedef struct {
	uint8_t Sender;
	uint8_t Bytes[256];
	uint8_t ResponceID;
	uint16_t BytesLength;
	uint8_t Command;
	uint8_t LQI;
	BinaryFormat Format;
} BinaryPacket;

uint8_t checksum(uint8_t *data, uint16_t length) {
	int i, sum = 0;
	for (i = 0; i < length; i++) {
		sum = sum ^ *data;
		data++;
	}
	return sum;
}

void AnalyzePacket(uint8_t *Packet, uint16_t PacketLength, BinaryPacket *Binary) {
	if (*Packet == 0xDB) {
		Binary->Format = Response;
		return;
	}
	Binary->Sender = *Packet;
	Packet++;
	if (*Packet < 0x80) {
		Binary->Format = Simplicity;
		Binary->Command = *Packet;
		Binary->BytesLength = packetLength - 2;
		memcpy(Binary->Bytes, Packet + 1, Binary->BytesLength);
		} else if (*Packet == 0xA0) {
		Binary->Format = Extention;
		Packet++;
		Binary->ResponceID = *Packet;
		Packet = Packet + 9;
		Binary->LQI = *Packet;
		Packet++;
		Binary->BytesLength = *Packet << 8;
		Packet++;
		Binary->BytesLength = Binary->BytesLength + *Packet;
		memcpy(Binary->Bytes, Packet + 1, Binary->BytesLength);
	}
}

ISR(USART_RX_vect){
	uint8_t regVal = UDR0;
	switch (packetStatus) {
		case 0:
		if (regVal == 0xA5)
		packetStatus = 1;
		break;
		case 1:
		if (regVal == 0x5A) {
			packetStatus = 2;
			} else {
			packetStatus = 0;
			dataPointer = 0;
			packetLength = 0;
		}
		break;
		case 2:
		if (regVal == 0x80) {
			packetStatus = 3;
			} else {
			packetStatus = 0;
			dataPointer = 0;
			packetLength = 0;
		}
		break;
		case 3:
		packetLength = regVal;
		packetStatus = 4;
		break;
		case 4:
		if (dataPointer < packetLength) {
			packet[dataPointer] = regVal;
			dataPointer++;
			} else {
			if (regVal == checksum(packet, packetLength)) {
				packetStatus = 5;
				} else {
				packetStatus = 0;
				dataPointer = 0;
				packetLength = 0;
			}
		}
		break;
		case 5:
		if (regVal == 0x04) {
			BinaryPacket binary;
			AnalyzePacket(packet, packetLength, &binary);
			if (binary.Bytes[3]&(1<<2)){
				display[0].enable=true;
				}else{
				display[0].enable=false;
			}
			if (binary.Bytes[3]&(1<<1)){
				display[1].enable=true;
				}else{
				display[1].enable=false;
			}
			if (binary.Bytes[3]&(1<<0)){
				display[2].enable=true;
				}else{
				display[2].enable=false;
			}
			display[0].value=(double)binary.Bytes[0]/10+0.001;
			display[1].value=binary.Bytes[1];
			display[2].value=(double)binary.Bytes[2]/10+0.001;
			overflow=0;
		}
		packetStatus = 0;
		dataPointer = 0;
		packetLength = 0;
		break;
		default:
		break;
	}
}
#pragma endregion

int main(void)
{
	/*
	*ATmegaのUSARTは8MHzから115200bps用のクロックを作り出せない残念な仕様
	*しょうがないので一番近そうなクロックを作り出してやり、残りは内臓オシレータを校正していい感じにしてやる
	*今回の場合はOSCCALが72から86の範囲で正常動作したので、その中間の79を採用した
	*この値は個体差があるはずなので毎回設定する必要がある
	*/
	OSCCAL=79;
	SPI_MasterInit();
	USART_Init(8);
	
	#if ROULETTE
	display[0].enable=true;
	display[1].enable=true;
	display[2].enable=true;
	eeprom_busy_wait();
	uint8_t address=0;
	uint8_t _random=eeprom_read_byte(&address);
	srand(_random);
	Timer_Init();
	#endif

	while (1)
	{
		int i;
		for (i = 0; i < 12; i++){
			CS_LOW;
			if(i<8){
				SPI_MasterTransmit(1<<digits[i]);
				SPI_MasterTransmit(0);
			}
			else
			{
				SPI_MasterTransmit(0);
				SPI_MasterTransmit(1<<digits[i]);
			}
			SPI_MasterTransmit(number[i]);
			CS_HIGH;
			if(i<11)_delay_us(1000);
		}
		num2bin(display,number);

		overflow++;
		if (overflow>800)
		{
			display[0].enable=false;
			display[1].enable=false;
			display[2].enable=false;
			overflow=0;
		}

		#if ROULETTE
		eeprom_busy_wait();
		eeprom_write_byte(&address,_random++);
		#endif
	}
}

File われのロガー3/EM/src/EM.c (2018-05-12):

/*
 ===============================================================================
 Name        : EM.c
 Author      : $(author)
 Version     :
 Copyright   : $(copyright)
 Description : main definition
 ===============================================================================
 */

#include "EM.h"
#include "ff.h"
#include "MotionDriver.h"
#include "gps.h"
#include "uart.h"
#include "interrupt.h"
#include "timer.h"
#include "microSD.h"
#include "comm.h"
#include "vcom.h"

FATFS fs;
FIL fp;

uint32_t time = 0;
uint8_t quat_flag = 0;
uint8_t gps_flag = 0;
volatile uint8_t save_flag = 0;
volatile uint8_t sendVcom_flag = 0;
volatile uint8_t sendgps_flag = 0;
volatile uint8_t checkdisconnect_flag = 0;
uint8_t instrument_flag = 0;
DATA nowdata;
uint32_t before, after;
LOGGER_STATUS *logger = &nowdata.logger;
QUAT_DATA *quat = &nowdata.quat;
GPS_DATA *gps = &nowdata.gps;
INSTRUMENT_DATA *air = &nowdata.air;
INSTRUMENT_DATA *tacho = &nowdata.tacho;
INSTRUMENT_DATA *alt = &nowdata.alt;
POWER_DATA *lp = &nowdata.left_power;
POWER_DATA *rp = &nowdata.right_power;

int main(void) {
	LPC_SYSCON->SYSPLLCLKSEL = 0x1;
	LPC_SYSCON->SYSPLLCLKUEN = 0x1;
	vcom_init();
	UART_Initialize(115200);
	SysTick_initialize();
	GPS_initialize();
	dmp_initialize(DMP_FREQUENCY);
	open_microSD(&fs, &fp);
	UART_printf("Logger start!\r\n");

	while (1) {
		if (quat_flag) {
			quat_flag = 0;
			int w;
			quat->more = 1;
			while (quat->more) {
				w = dmp_read_quat(quat);
				Timer32_0_start();
				if (w != -1) {
					quat2euler(quat);
					quat->delay = w;
					if (w == 1)
						quat->delay = 1;
					logger->fr = save_QUAT(&fp, quat);
					send_QUAT(quat);
					//UART_printf("while,%d,more,%d\r\n", w, quat->more);
				}
			}
			if (w == 1) {
				w = -1;
				//UART_printf("while error          %ld\r\n",						(long) (after - before));
				while (w == -1)
					w = dmp_read_quat(quat);
				Timer32_0_start();
				quat2euler(quat);
				quat->delay = w;
				if (w == 1)
					quat->delay = 1;
				logger->fr = save_QUAT(&fp, quat);
				send_QUAT(quat);
				//UART_printf("while,%d,more,%d\r\n", w, quat->more);
			}
			save_flag++;
			if (save_flag == 5) {
				before = time;
				logger->fr = f_sync(&fp);
				after = time;
				//UART_printf("%ld\r\n", (long) (after - before));
			}
			sendVcom_flag++;
			if (sendVcom_flag == 10) {
				send_PC(&nowdata);
			}
			checkdisconnect_flag++;
			if (checkdisconnect_flag == 15) {
				check_connection(&nowdata);
			}
			if (sendgps_flag) {
				sendgps_flag = 0;
				send_GPS(gps);
			}
			if (gps_flag) {
				uint16_t length = GPS_fifo_length();
				if (!length)
					continue;
				gps_flag = 0;
				uint8_t data[length];
				if (GPS_read_fifo(data, length) == 0xB5620107) {
					GPS_read_NAV_PVT(data, gps);
					logger->fr = save_GPS(&fp, gps->timestamp, gps->TPvalid,
							data);
				} else {
					UART_printf("error len:%d\r\n", length);
				}
				save_flag = 0;
				sendVcom_flag = 0;
				checkdisconnect_flag = 0;
				sendgps_flag = 1;
			}
			if (instrument_flag) {
				if (instrument_flag & (1 << 0)) {
					instrument_flag &= ~(1 << 0);
					logger->fr = save_Instrument(&fp, 0x03, air);
				}
				if (instrument_flag & (1 << 1)) {
					instrument_flag &= ~(1 << 1);
					logger->fr = save_Instrument(&fp, 0x04, tacho);
				}
				if (instrument_flag & (1 << 2)) {
					instrument_flag &= ~(1 << 2);
					logger->fr = save_Instrument(&fp, 0x05, alt);
				}
				if (instrument_flag & (1 << 3)) {
					instrument_flag &= ~(1 << 3);
					logger->fr = save_PowerMeter(&fp, 0x06, lp);
				}
				if (instrument_flag & (1 << 4)) {
					instrument_flag &= ~(1 << 4);
					logger->fr = save_PowerMeter(&fp, 0x07, rp);
				}
			}
		}
		if (logger->fr != FR_OK)
			open_microSD(&fs, &fp);
	}
	return 0;
}
